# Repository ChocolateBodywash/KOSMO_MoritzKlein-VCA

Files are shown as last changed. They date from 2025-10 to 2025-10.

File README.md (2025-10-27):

## KOSMO Format Moritz Klein VCA

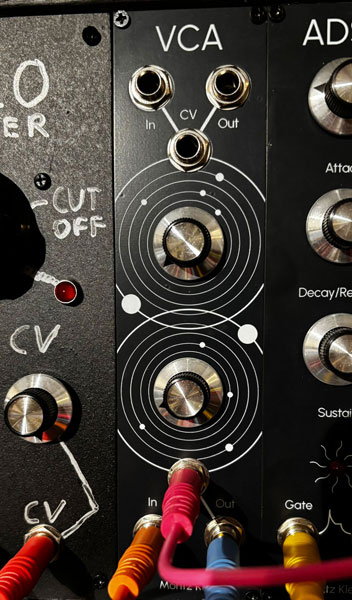
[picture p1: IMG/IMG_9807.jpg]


A KOSMO format of Moritz Klein’s VCA

Moritz Klein’s VCA (https://www.youtube.com/watch?v=yMrCCx6uqcE)

This was my first dip into PCB design and oh boy, it would have made more sense to start with the simpler ADSR. There were a lot of things I could have done more efficiently and possibly better (adding normalization between VCAs) but it works.

---
Note: This was created by a hobbyist with no formal engineering training outside various late night YouTube binges. 
I’ve confirmed these designs to work but I make no guarantees on the design working efficiently.. or working at all.

Additional credit: Analog Output (Richard Holmes) for footprint libraries and front panel templates.

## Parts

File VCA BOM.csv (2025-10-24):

Reference | Value | Datasheet | Package | Qty
C1,C2 | 47uF | ~ | Electrolytic Capacitor | 2
C3,C4,C5,C6,C7,C8 | 0.1uF | ~ | Ceramic Disc Capacitor | 6
D1,D2 | 1N5819 | http://www.vishay.com/docs/88525/1n5817.pdf | Diode_THT:D_DO-41_SOD81_P10.16mm_Horizontal | 2
E1 | Conn_02x05_Pin | ~ | Pins_2x05_2.54mm_TH_EurorackPower_Shrouded | 1
J1 | Signal In 1 | ~ | Jack_6.35mm | 1
J2 | Out 1 | ~ | Jack_6.35mm | 1
J3 | CV In 1 | ~ | Jack_6.35mm | 1
J4 | Signal In 2 | ~ | Jack_6.35mm | 1
J5 | Out 2 | ~ | Jack_6.35mm | 1
J6 | CV In 2 | ~ | Jack_6.35mm | 1
J7,J8,J9,J10 | Conn_01x06 | ~ | Connector_PinHeader_2.54mm:PinHeader_1x06_P2.54mm_Vertical | 4
Q1,Q2,Q3,Q4 | BC548 | https://www.onsemi.com/pub/Collateral/BC550-D.pdf | Package_TO_SOT_THT:TO-92_Inline | 4
VR1,VR2 | B100K |  | Potentiometer_Alpha_RD901F-40-00D_Single_Vertical
R1,R2 | 10 | ~ | Metal Film 1/4 Resistor | 2
R3,R4,R5,R6,R9,R10,R21,R22,RV1,RV2 | 100K | ~ | Metal Film 1/4 Resistor | 12
R7,R8 | 82K | ~ | Metal Film 1/4 Resistor | 2
R11,R12,R19,R20 | 100 | ~ | Metal Film 1/4 Resistor | 4
R13,R14,R17,R18 | 20K m | ~ | Metal Film 1/4 Resistor | 4
R15,R16 | 10K | ~ | Metal Film 1/4 Resistor | 2
R23,R24,R25,R26 | 10K m | ~ | Metal Film 1/4 Resistor | 4
R27,R28,R29,R30 | 100K m | ~ | Metal Film 1/4 Resistor | 4
R31,R32 | 1K | ~ | Metal Film 1/4 Resistor | 2
R33,R34 | 20K | ~ | Metal Film 1/4 Resistor | 2
U1,U2 | TL072 | http://www.ti.com/lit/ds/symlink/tl071.pdf | DIP-8_W7.62mm | 2

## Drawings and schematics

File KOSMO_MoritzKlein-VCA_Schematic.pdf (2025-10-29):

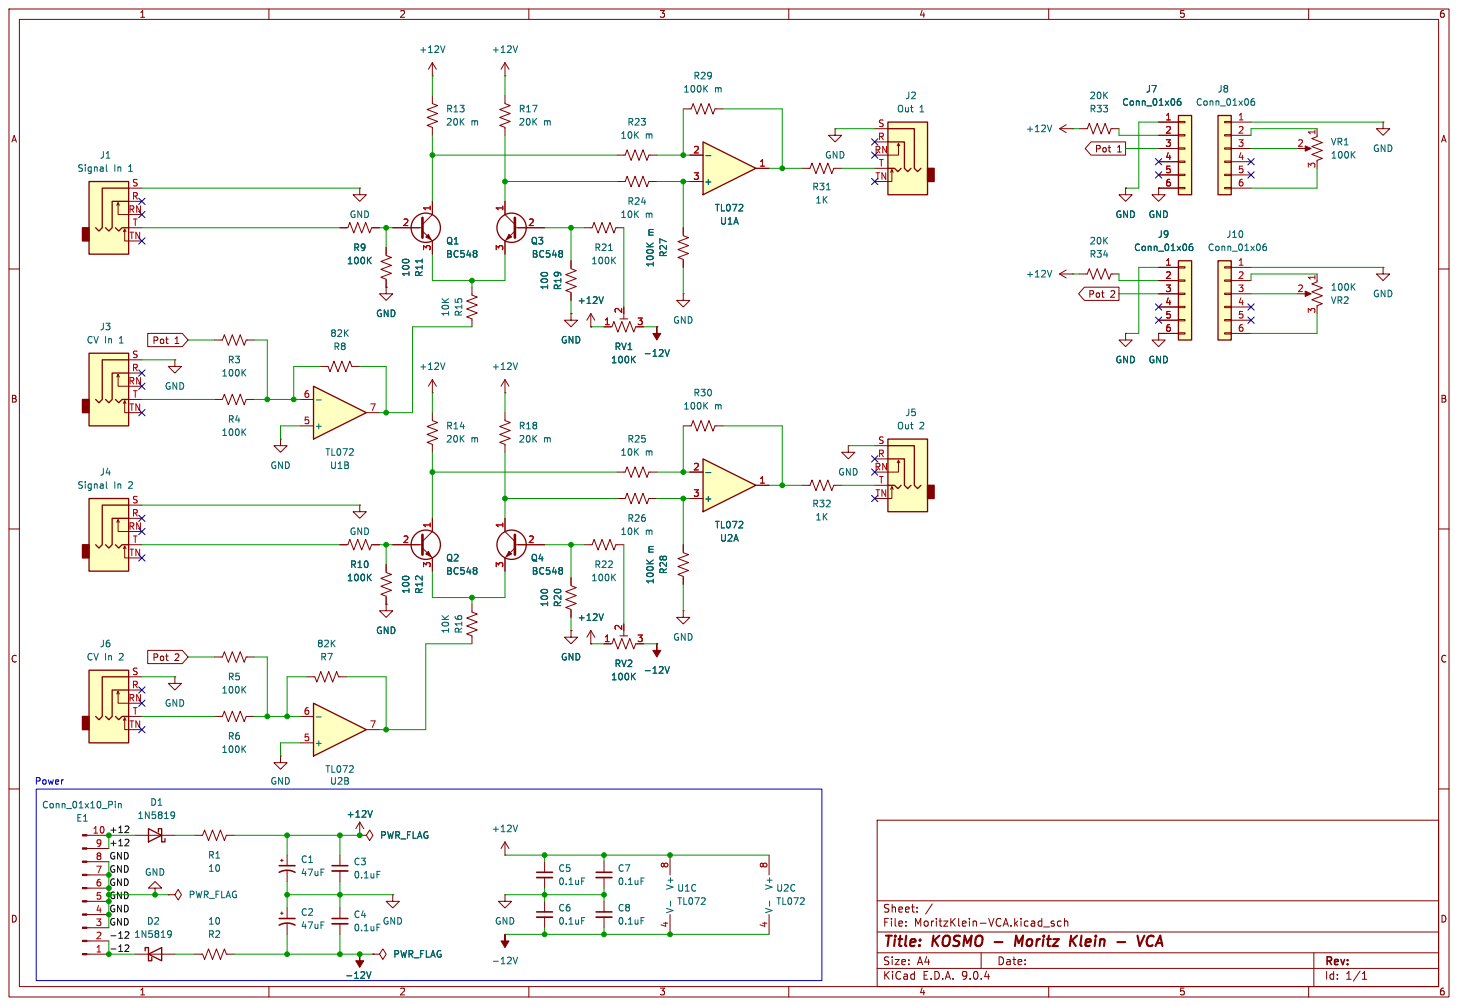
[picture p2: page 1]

File: MoritzKlein-VCA.kicad_sch Sheet: /
Id: 1/1 Title: KOSMO - Moritz Klein - VCA

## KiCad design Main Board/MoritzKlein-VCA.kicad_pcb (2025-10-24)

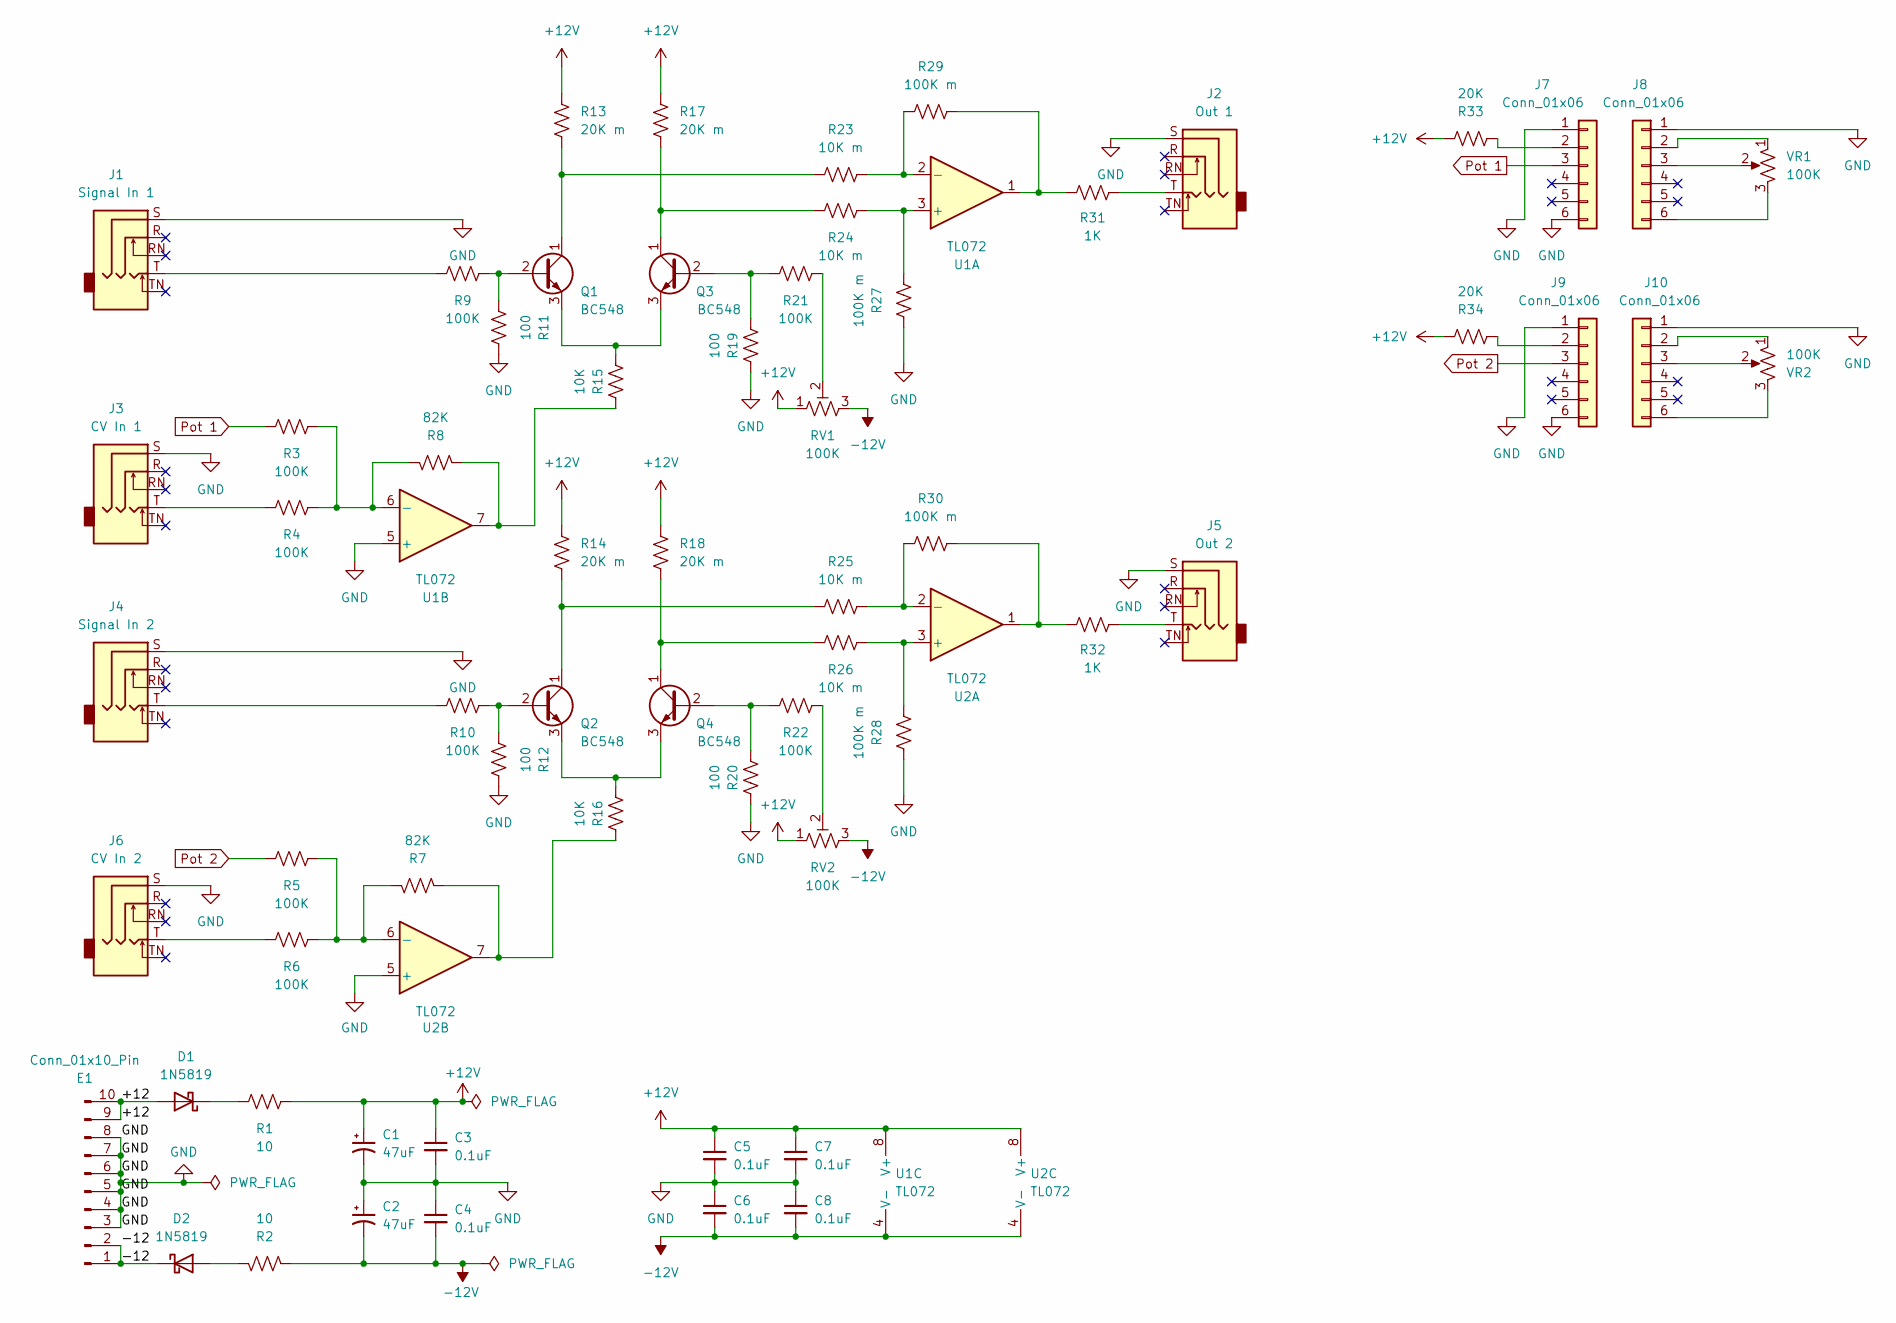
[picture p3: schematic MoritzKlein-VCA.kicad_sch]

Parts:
C1, C2: 47uF; CP_Radial_D5.0mm_P2.50mm
C3, C4, C5, C6, C7, C8: 0.1uF; C_Disc_D3.0mm_W1.6mm_P2.50mm
D1, D2: 1N5819; D_DO-41_SOD81_P10.16mm_Horizontal
E1: Conn_01x10_Pin; Pins_2x05_2.54mm_TH_EurorackPower_Shrouded
J1: Signal In 1; Jack_6.35mm_PJ_629HAN
J2: Out 1; Jack_6.35mm_PJ_629HAN
J3: CV In 1; Jack_6.35mm_PJ_629HAN
J4: Signal In 2; Jack_6.35mm_PJ_629HAN
J5: Out 2; Jack_6.35mm_PJ_629HAN
J6: CV In 2; Jack_6.35mm_PJ_629HAN
J7, J8, J9, J10: Conn_01x06; PinHeader_1x06_P2.54mm_Vertical
Q1, Q2, Q3, Q4: BC548; TO-92_Inline
R1, R2: 10; R_Axial_DIN0207_L6.3mm_D2.5mm_P10.16mm_Horizontal
R3, R4, R5, R6, R9, R10, R21, R22: 100K; R_Axial_DIN0207_L6.3mm_D2.5mm_P10.16mm_Horizontal
R7, R8: 82K; R_Axial_DIN0207_L6.3mm_D2.5mm_P10.16mm_Horizontal
R11, R12, R19, R20: 100; R_Axial_DIN0207_L6.3mm_D2.5mm_P10.16mm_Horizontal
R13, R14, R17, R18: 20K m; R_Axial_DIN0207_L6.3mm_D2.5mm_P10.16mm_Horizontal
R15, R16: 10K; R_Axial_DIN0207_L6.3mm_D2.5mm_P10.16mm_Horizontal
R23, R24, R25, R26: 10K m; R_Axial_DIN0207_L6.3mm_D2.5mm_P10.16mm_Horizontal
R27, R28, R29, R30: 100K m; R_Axial_DIN0207_L6.3mm_D2.5mm_P10.16mm_Horizontal
R31, R32: 1K; R_Axial_DIN0207_L6.3mm_D2.5mm_P10.16mm_Horizontal
R33, R34: 20K; R_Axial_DIN0207_L6.3mm_D2.5mm_P10.16mm_Horizontal
RV1, RV2: 100K; Potentiometer_Bourns_3296W_Vertical
U1, U2: TL072; DIP-8pin_TH
VR1, VR2: 100K; Potentiometer_Alpha_RD901F-40-00D_Single_Vertical

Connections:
+12V: C1.1, C3.1, C5.1, C7.1, R1.2, R13.1, R14.1, R17.1, R18.1, R33.2, R34.2, RV1.1, RV2.1, U1.8 (V+), U2.8 (V+)
-12V: C2.2, C4.2, C6.2, C8.2, R2.2, RV1.3, RV2.3, U1.4 (V-), U2.4 (V-)
/+12: D1.2 (A), E1.9, E1.10
/-12: D2.1 (K), E1.1, E1.2
GND: C1.2, C2.1, C3.2, C4.1, C5.2, C6.1, C7.2, C8.1, E1.3, E1.4, E1.5, E1.6, E1.7, E1.8, J1.S, J2.S, J3.S, J4.S, J5.S, J6.S, J7.1, J7.6, J8.1, J9.1, J9.6, J10.1, R11.2, R12.2, R19.2, R20.2, R27.2, R28.2, U1.5 (+), U2.5 (+)
unnamed: D1.1 (K), R1.1
unnamed: D2.2 (A), R2.1
unnamed: J1.T, R9.1
unnamed: J2.T, R31.2
unnamed: J3.T, R4.1
unnamed: J4.T, R10.1
unnamed: J5.T, R32.2
unnamed: J6.T, R6.1
unnamed: J7.2, R33.1
unnamed: J8.2, VR1.1
unnamed: J8.3, VR1.2
unnamed: J8.6, VR1.3
unnamed: J9.2, R34.1
unnamed: J10.2, VR2.1
unnamed: J10.3, VR2.2
unnamed: J10.6, VR2.3
unnamed: Q1.2 (B), R9.2, R11.1
unnamed: Q1.1 (C), R13.2, R23.1
unnamed: Q1.3 (E), Q3.3 (E), R15.1
unnamed: Q2.2 (B), R10.2, R12.1
unnamed: Q2.1 (C), R14.2, R25.1
unnamed: Q2.3 (E), Q4.3 (E), R16.1
unnamed: Q3.2 (B), R19.1, R21.1
unnamed: Q3.1 (C), R17.2, R24.1
unnamed: Q4.2 (B), R20.1, R22.1
unnamed: Q4.1 (C), R18.2, R26.1
unnamed: R8.2, R15.2, U1.7
unnamed: R7.2, R16.2, U2.7
unnamed: R21.2, RV1.2
unnamed: R22.2, RV2.2
unnamed: R29.2, R31.1, U1.1
unnamed: R30.2, R32.1, U2.1
unnamed: R24.2, R27.1, U1.3 (+)
unnamed: R23.2, R29.1, U1.2 (-)
unnamed: R3.2, R4.2, R8.1, U1.6 (-)
unnamed: R26.2, R28.1, U2.3 (+)
unnamed: R25.2, R30.1, U2.2 (-)
unnamed: R5.2, R6.2, R7.1, U2.6 (-)
Pot 1: J7.3, R3.1
Pot 2: J9.3, R5.1

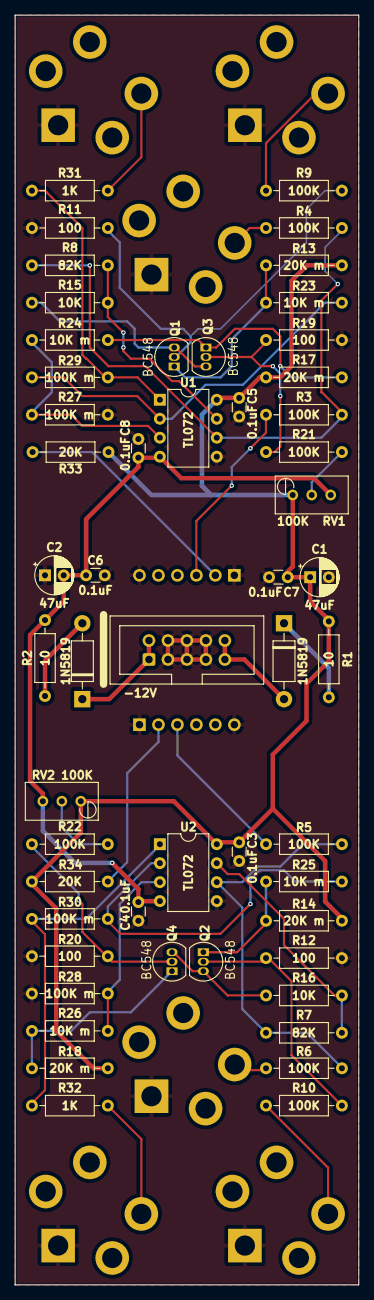
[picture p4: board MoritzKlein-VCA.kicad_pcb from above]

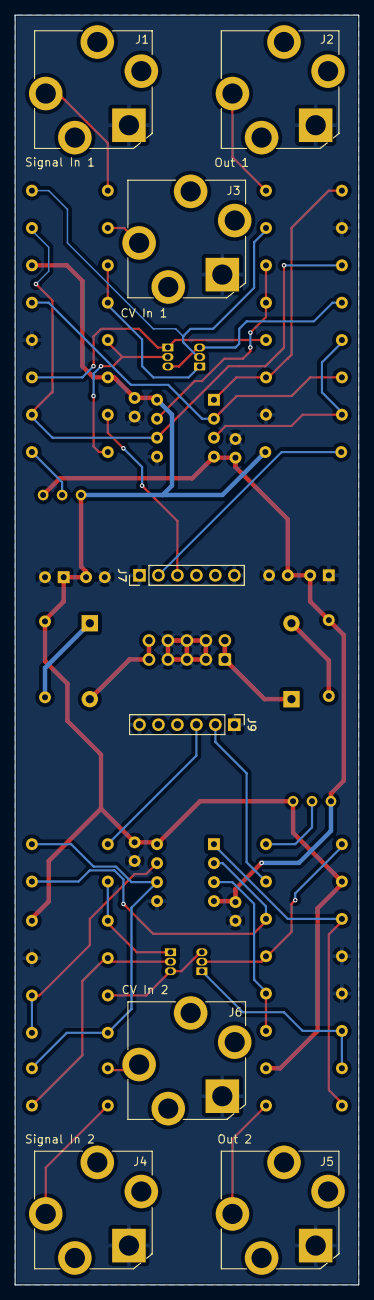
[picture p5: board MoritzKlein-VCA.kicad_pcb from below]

Board: 2 copper layers, 46.0 x 170.0 mm, 61 parts (8 on the bottom side), 39 nets.

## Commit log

2025-10-24 Create VCA BOM.csv
    [VCA BOM.csv]
2025-10-29 Upload Schematics
    [MoritzKlein-VCA.kicad_sch]
